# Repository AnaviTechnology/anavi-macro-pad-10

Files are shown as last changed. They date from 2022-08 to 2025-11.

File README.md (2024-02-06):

# ANAVI Macro Pad 10

**Open source programmable keypad with 9 mechanical switches and a rotary encoder.**

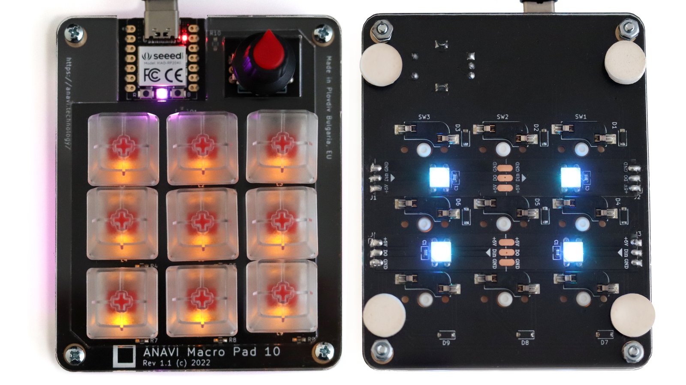
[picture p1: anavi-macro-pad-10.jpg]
ANAVI Macro Pad 10


ANAVI Macro Pad 10 is an open source, custom-programmable, mini keyboard/keypad.

ANAVI Macro Pad 10 has been designed with [the cross platform and open source electronics design automation suite KiCad](https://kicad.org/). Compatible with [KMK firmware](https://github.com/KMKfw/kmk_firmware/tree/master/boards/anavi/macro-pad-10) and [QMK firmware](https://github.com/qmk/qmk_firmware/tree/master/keyboards/anavi).

[ANAVI Macro Pad 10, ANAVI Knob 1 and ANAVI Knobs 3 were brought to market through a crowdfunding campaign at Crowd Supply](https://www.crowdsupply.com/anavi-technology/anavi-macro-pad-10). For more details please visit https://anavi.technology/

# License

The project is released under the [Creative Commons Attribution-ShareAlike 4.0 International (CC BY-SA 4.0)](https://creativecommons.org/licenses/by-sa/4.0/).

Note: This is a human-readable summary of (and not a substitute for) the [license](https://creativecommons.org/licenses/by-sa/4.0/legalcode).

You are free to:

Share — copy and redistribute the material in any medium or format Adapt — remix, transform, and build upon the material for any purpose, even commercially. The licensor cannot revoke these freedoms as long as you follow the license terms. Under the following terms:

Attribution — You must give appropriate credit, provide a link to the license, and indicate if changes were made. You may do so in any reasonable manner, but not in any way that suggests the licensor endorses you or your use. ShareAlike — If you remix, transform, or build upon the material, you must distribute your contributions under the same license as the original. No additional restrictions — You may not apply legal terms or technological measures that legally restrict others from doing anything the license permits. Notices:

You do not have to comply with the license for elements of the material in the public domain or where your use is permitted by an applicable exception or limitation. No warranties are given. The license may not give you all of the permissions necessary for your intended use. For example, other rights such as publicity, privacy, or moral rights may limit how you use the material.

You will have to provide a link to the original creator of the project http://www.anavi.technology on any documentation or website.

Credit can be attributed through a link to the creator website: http://www.anavi.technology

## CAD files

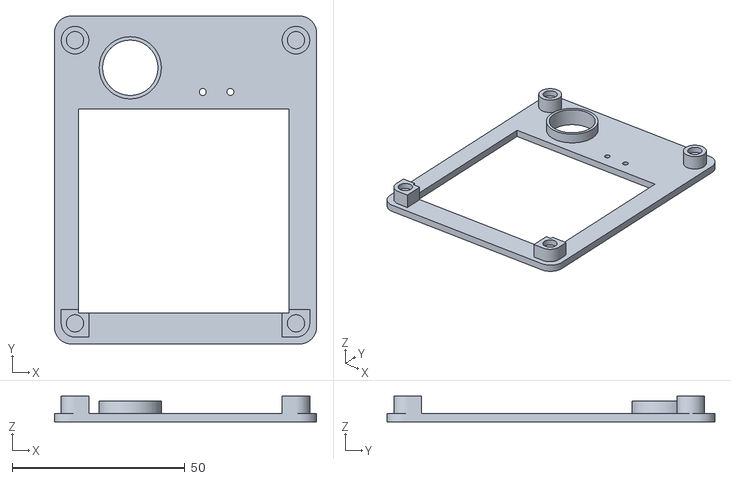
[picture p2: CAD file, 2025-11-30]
case/anavi-macro-pad-10-top.stl
76.0 x 95.0 x 7.50

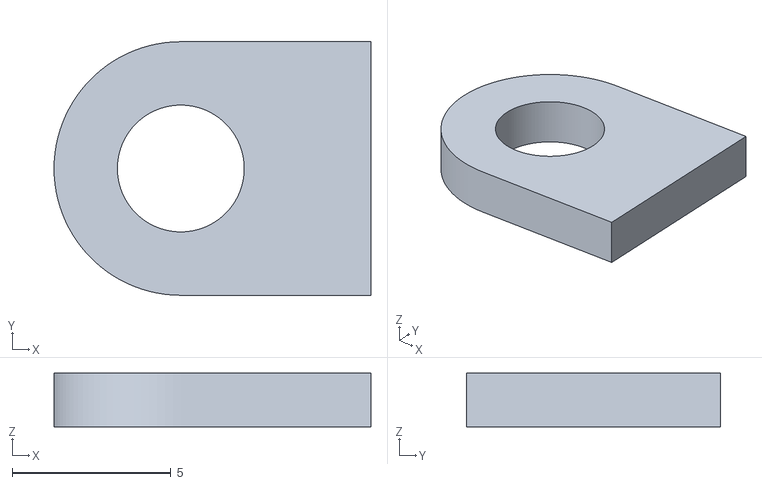
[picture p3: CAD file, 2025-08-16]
case/keyboard-spacer-17.stl
10.0 x 8.00 x 1.70

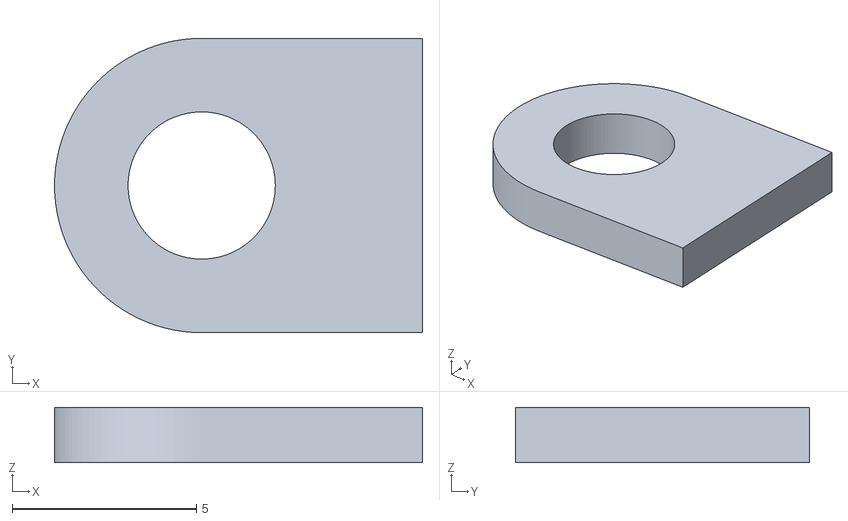
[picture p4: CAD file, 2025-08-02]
case/keyboard-spacer.stl
10.0 x 8.00 x 1.50

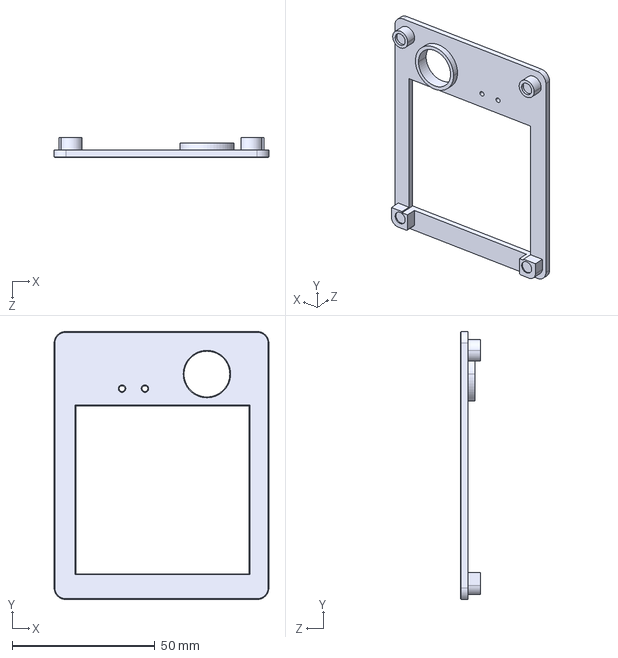
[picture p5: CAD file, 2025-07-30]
case/anavi-macro-pad-10-case-top.step
75.2 x 93.8 x 7.10 mm

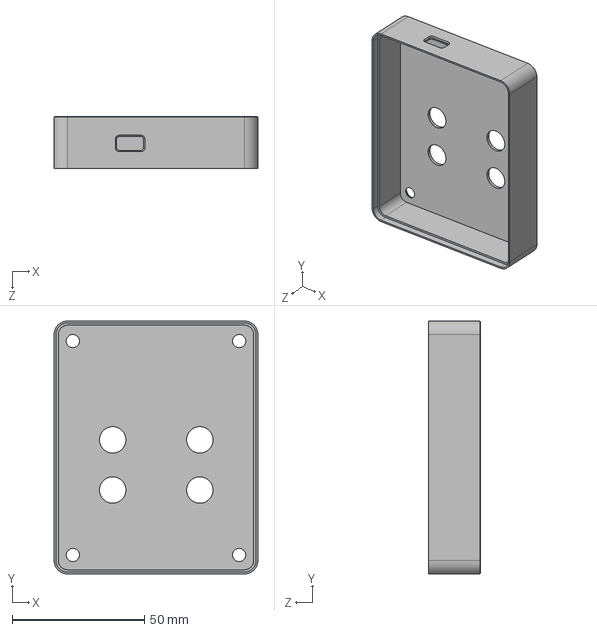
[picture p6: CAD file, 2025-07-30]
case/anavi-macro-pad-10-case-bottom.step
77.2 x 95.8 x 19.7 mm

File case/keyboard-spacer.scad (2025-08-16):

// Settings

// Height of the keyboard spacer
height = 1.7;
// Outer diameter of the main cylinder
outer_d = 8;
// Diameter of the hole
inner_d = 4;
// Width of the rectangular extension
rect_w = 6;
// Height (depth in X-Y) of the rectangular extension
rect_h = 8;

module base_shape() {
    difference() {
        union() {
            // Main cylinder
            cylinder(h=height, d=outer_d, $fn=100);
            
            // Rectangular cuboid on the right
            // which starts at the middle of the cylinder
            translate([0, -rect_h/2, 0])
                cube([rect_w, rect_h, height]);
        }

        // Inner hole
        cylinder(h=height + 0.1, d=inner_d, $fn=100);
    }
}

// Render the 3D object
base_shape();

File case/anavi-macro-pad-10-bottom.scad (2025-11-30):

// ========================
// Parameters
// ========================
corner_r = 5;    // PCB corner radius

wall_thickness = 2;  // Wall thickness
$fn = 64;              // smooth corners


// Case
case_width = 78;
case_lenght = 97;
case_height = 20;

// Outer cylinder
outer_r = 3;
outer_h = 4;

// Inner hole
hole_r = 3;
hole_h = 2;

// USB-C connector
usbc_l = 10;
usbc_h = 5;

// LED
led_r = 5;

// increase for smoother cone ($fn)
segments = 64;

// ========================
// Case Top Module
// ========================
module case_top() {

    // Translate so inner PCB pocket starts at (0,0)
    translate([corner_r, corner_r, 0]) {
        difference() {
            // Outer shell (walls included)
            linear_extrude(height = case_height)
                rounded_rect(case_width,
                             case_lenght,
                             corner_r);

            // Main hollow interior
            translate([wall_thickness, wall_thickness, wall_thickness])
                linear_extrude(height = case_height-3)
                    rounded_rect(case_width-2*wall_thickness, case_lenght-2*wall_thickness, corner_r);
            
            // Top hollow interior
            translate([wall_thickness/2, wall_thickness/2, case_height-3])
                linear_extrude(height = 3)
                    rounded_rect(case_width-wall_thickness, case_lenght-wall_thickness, corner_r);

            // Mounting hole 1 (top left)
            translate([2, case_lenght-4.5-hole_r*3, 0])
                // Cone
                cylinder(wall_thickness, hole_r, hole_h, center = false, $fn = segments);
            
            // Mounting hole 2 (top right)
            translate([case_width-4.5-hole_r*3+1, case_lenght-4.5-hole_r*3, 0])
                // Cone
                cylinder(wall_thickness, hole_r, hole_h, center = false, $fn = segments);

            // Mounting hole 2 (top right)
            translate([case_width-4.5-hole_r*3+1, hole_h, 0])
                // Cone
                cylinder(wall_thickness, hole_r, hole_h, center = false, $fn = segments);
            
            // Mounting hole 4 (bottom left)
            translate([2, 2, 0])
                // Cone
                cylinder(wall_thickness, hole_r, hole_h, center = false, $fn = segments);
                
            // WS2812B LEDs
            
            // LED bottom left
            translate([17.5, 27, 0])
                cylinder(h = wall_thickness, r = led_r, $fn = segments);
                
            // LED top left
            translate([17.5, 46, 0])
                cylinder(h = wall_thickness, r = led_r, $fn = segments);
                
            // LED bottom right
            translate([50.5, 27, 0])
                cylinder(h = wall_thickness, r = led_r, $fn = segments);
            
            // LED top right
            translate([50.5, 46, 0])
                cylinder(h = wall_thickness, r = led_r, $fn = segments);
            
        }
    }
}

// ========================
// Rounded rectangle module
// ========================
module rounded_rect(x, y, radius) {
    minkowski() {
        square([x - 2*radius, y - 2*radius], center = false);
        circle(r = radius, $fn = $fn);
    }
}

// ========================
// Mounting hole
// ========================
module mounting_hole() {
    difference() {
        // Outer cylinder
        cylinder(h = outer_h, r = outer_r, $fn = 64);
        
        // Inner hole
        translate([0, 0, outer_h-hole_h])  // hole starts at base
            cylinder(h = hole_h, r = hole_r, $fn = 64);
    }
}

module usbc() {
    rotate([90,0,0])
        linear_extrude(height = wall_thickness)
            rounded_rect(usbc_l,usbc_h,1);
}

// ========================
// Top case
// ========================

difference() {
    // Main part of the case
    case_top();  
    // USB-C connector
    translate([1+24, case_lenght, 1+7.8])
       usbc();
}

// ========================
// Visual Tests
// ========================
/*
// Check LED bottom left
translate([0, 27, -10])
    cube([17.5, 10, 30]);

// Check LED top left
translate([0, 46, -10])
    cube([17.5, 10, 30]);

// Check USB-C shorter distance
translate([0, case_lenght, -10])
    cube([24, 4.5, 30]);

// Check USB-C height from bottom
translate([0, case_lenght, 0])
    cube([34, 4.5, 7.8]);

// Check mounting hole 1
translate([0, case_lenght-4.5-20, -10])
    cube([4.5, 20, 30]); 
translate([0, case_lenght-4.5, -10])
    cube([20, 4.5, 30]);

// Check mounting hole 2
translate([case_width-4.5, case_lenght-4.5-20, -10])
    cube([4.5, 20, 30]); 
translate([case_width-20, case_lenght-4.5, -10])
    cube([20, 4.5, 30]);

// Check mounting hole 3
translate([case_width-4.5, 0, -10])
    cube([4.5, 20, 30]); 
translate([case_width-20, 0, -10])
    cube([20, 4.5, 30]);

// Check mounting hole 4
translate([0, 0, -10])
    cube([4.5, 20, 30]); 
translate([0, 0, -10])
    cube([20, 4.5, 30]);
*/

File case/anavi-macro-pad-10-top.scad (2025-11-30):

// ========================
// Parameters
// ========================
// PCB corner radius
corner_r = 5;    
// Wall thickness
wall_thickness = 2;  
// smooth corners
$fn = 64;              


// Case (2 mm shorter than the bottom, aka 1 mm on each side)
case_width = 76;
case_lenght = 95;
case_height = 2.5;

// Outer cylinder
outer_r = 4;
outer_h = 5;

// Inner hole
hole_r = 2.5;
hole_h = 2;

// USB-C connector
usbc_l = 10;
usbc_h = 5;

// LED
led_r = 5;

// increase for smoother cone ($fn)
segments = 64;

// ========================
// Case Top Module
// ========================

module case_top() {
    difference() {
        
        // Translate so inner PCB pocket starts at (0,0)
        union() {
            
            translate([corner_r, corner_r, 0])
            // Outer shell (walls included)
            linear_extrude(height = case_height)
                rounded_rect(case_width,
                             case_lenght,
                             corner_r);
            
            // Rotary encoder border
            translate([13+9, 71+9, 0])
                cylinder(6, 9, 9, $fn = segments);
            
            // Bottom left
            translate([2, 2, case_height])
                mounting_hole(true);
            
            // Bottom right
            translate([case_width-2*outer_r-2, 2, case_height])
                mounting_hole(false);
            
            // Top left
            translate([2, case_lenght-2*outer_r-3, case_height])
                mounting_hole_round();
            
            // Top right
            translate([case_width-2*outer_r-2, case_lenght-2*outer_r-3, case_height])
                mounting_hole_round();
        }
        
        // Inner hollow segment of the keycaps
        translate([7, 9, 0])
            cube([61, 59, 30]);
        
        // Opening for the rotary encoder
        translate([14+8, 72+8, 0])
            cylinder(6, 8, 8, $fn = segments);
        
        // Openings for the buttons
        translate([43, 73, 0])
            cylinder(3, 1, 1, $fn = segments);
        
        translate([51, 73, 0])
            cylinder(3, 1, 1, $fn = segments);
    }
    
}

// ========================
// Rounded rectangle module
// ========================
module rounded_rect(x, y, radius) {
    minkowski() {
        square([x - 2*radius, y - 2*radius], center = false);
        circle(r = radius, $fn = $fn);
    }
}

// ========================
// Mounting holes
// ========================
module mounting_hole_round() {
    // Position at start
    translate([outer_r, outer_r, 0]) {
        difference() {
            // Outer cylinder
            cylinder(h = outer_h, r = outer_r, $fn = segments);
            
            // Inner hole
            translate([0, 0, outer_h-hole_h])
                cylinder(h = hole_h, r = hole_r, $fn = segments);
        }
    }
}

module mounting_hole(left = true) {
    tr = left ? 0 : -outer_r;
    // Position at start
    translate([outer_r, outer_r, 0]) {
        difference() {
            
            union() {
                // Outer cylinder
                cylinder(h = outer_h, r = outer_r, $fn = segments);
                translate([tr, -outer_r, 0])
                    cube([4, 8, outer_h]);
                translate([-outer_r, 0, 0])
                    cube([8, 4, outer_h]);
            }
            
            // Inner hole
            translate([0, 0, outer_h-hole_h])
                cylinder(h = hole_h, r = hole_r, $fn = segments);
        }
    }
}

// ========================
// Top case
// ========================

case_top();

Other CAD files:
case/anavi-macro-pad-10-case-bottom.stl
case/anavi-macro-pad-10-case-top.stl

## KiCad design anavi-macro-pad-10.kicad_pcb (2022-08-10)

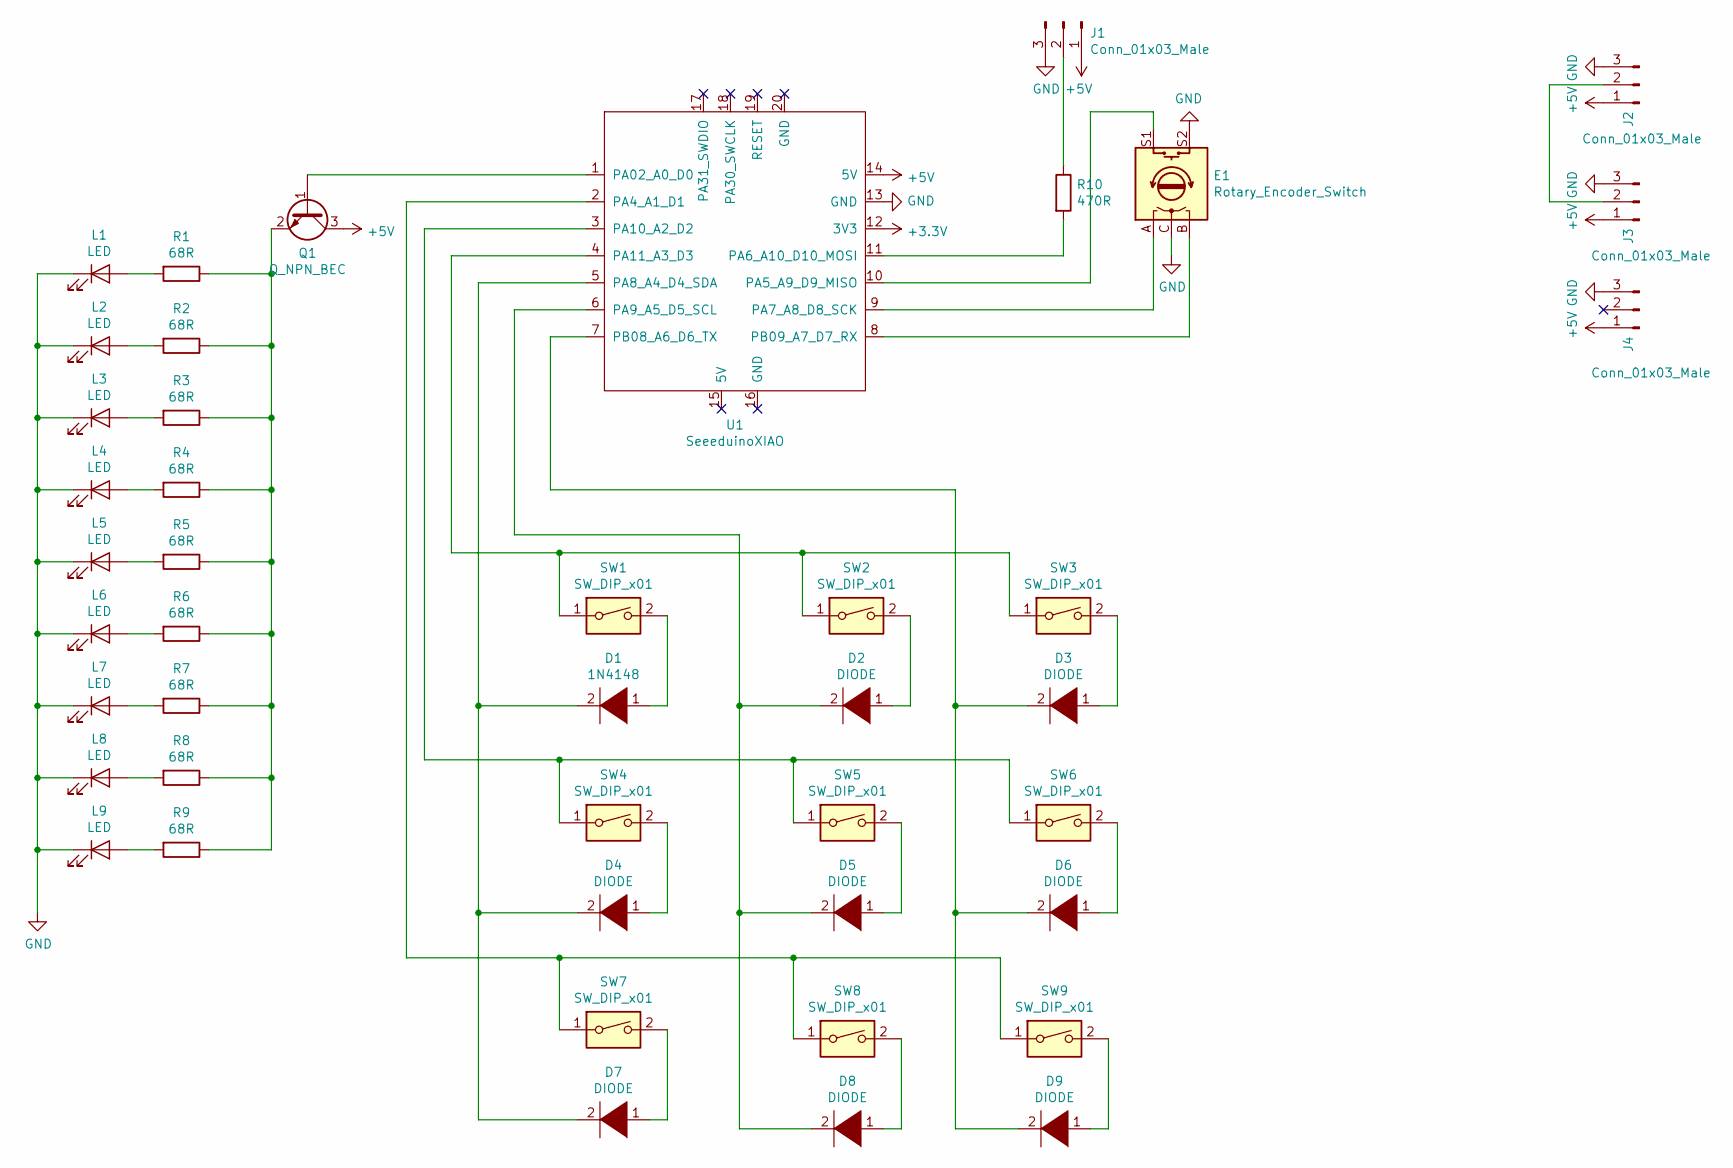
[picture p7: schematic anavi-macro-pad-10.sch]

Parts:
D1: 1N4148; D_SOD-123
D2, D3, D4, D5, D6, D7, D8, D9: DIODE; D_SOD-123
E1: Rotary_Encoder_Switch; RotaryEncoder_Alps_EC11E-Switch_Vertical_H20mm
J1, J2, J3, J4: Conn_01x03_Male; LedConnector_1x03_P2.54mm
L1, L2, L3, L4, L5, L6, L7, L8, L9: LED; LED_1206_3216Metric
Q1: Q_NPN_BEC; SOT-23
R1, R2, R3, R4, R5, R6, R7, R8, R9: 68R; R_0603_HandSoldering
R10: 470R; R_0603_HandSoldering
SW1, SW2, SW3, SW4, SW5, SW6, SW7, SW8, SW9: SW_DIP_x01; Kailh_socket_MX
U1: SeeeduinoXIAO; Seeeduino XIAO-MOUDLE14P-2.54-21X17.8MM

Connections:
+5V: J1.1, J2.1, J3.1, J4.1, Q1.3 (C), U1.14 (5V)
GND: E1.C, E1.S2, J1.3, J2.3, J3.3, J4.3, L1.1 (K), L2.1 (K), L3.1 (K), L4.1 (K), L5.1 (K), L6.1 (K), L7.1 (K), L8.1 (K), L9.1 (K), U1.13 (GND)
unnamed: D1.1 (K), SW1.2
unnamed: D1.2 (A), D4.2 (A), D7.2 (A), U1.5 (PA8_A4_D4_SDA)
unnamed: D2.1 (K), SW2.2
unnamed: D2.2 (A), D5.2 (A), D8.2 (A), U1.6 (PA9_A5_D5_SCL)
unnamed: D3.1 (K), SW3.2
unnamed: D3.2 (A), D6.2 (A), D9.2 (A), U1.7 (PB08_A6_D6_TX)
unnamed: D4.1 (K), SW4.2
unnamed: D5.1 (K), SW5.2
unnamed: D6.1 (K), SW6.2
unnamed: D7.1 (K), SW7.2
unnamed: D8.1 (K), SW8.2
unnamed: D9.1 (K), SW9.2
unnamed: E1.A, U1.9 (PA7_A8_D8_SCK)
unnamed: E1.B, U1.8 (PB09_A7_D7_RX)
unnamed: E1.S1, U1.10 (PA5_A9_D9_MISO)
unnamed: J1.2, R10.1
unnamed: J2.2, J3.2
unnamed: L1.2 (A), R1.2
unnamed: L2.2 (A), R2.2
unnamed: L3.2 (A), R3.2
unnamed: L4.2 (A), R4.2
unnamed: L5.2 (A), R5.2
unnamed: L6.2 (A), R6.2
unnamed: L7.2 (A), R7.2
unnamed: L8.2 (A), R8.2
unnamed: L9.2 (A), R9.2
unnamed: Q1.1 (B), U1.1 (PA02_A0_D0)
unnamed: Q1.2 (E), R1.1, R2.1, R3.1, R4.1, R5.1, R6.1, R7.1, R8.1, R9.1
unnamed: R10.2, U1.11 (PA6_A10_D10_MOSI)
unnamed: SW1.1, SW2.1, SW3.1, U1.4 (PA11_A3_D3)
unnamed: SW4.1, SW5.1, SW6.1, U1.3 (PA10_A2_D2)
unnamed: SW7.1, SW8.1, SW9.1, U1.2 (PA4_A1_D1)

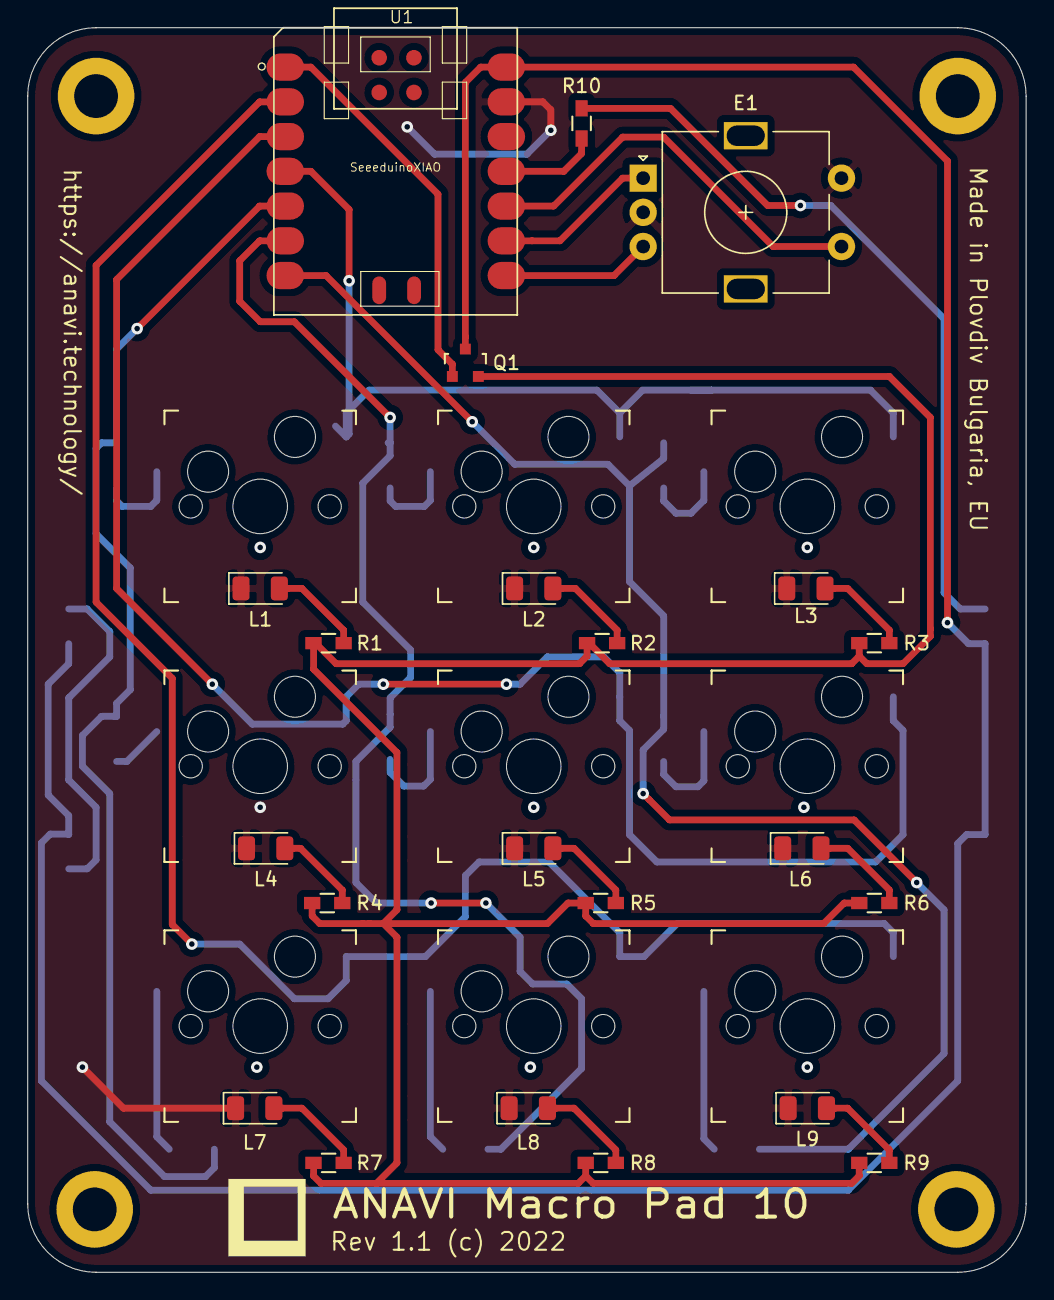
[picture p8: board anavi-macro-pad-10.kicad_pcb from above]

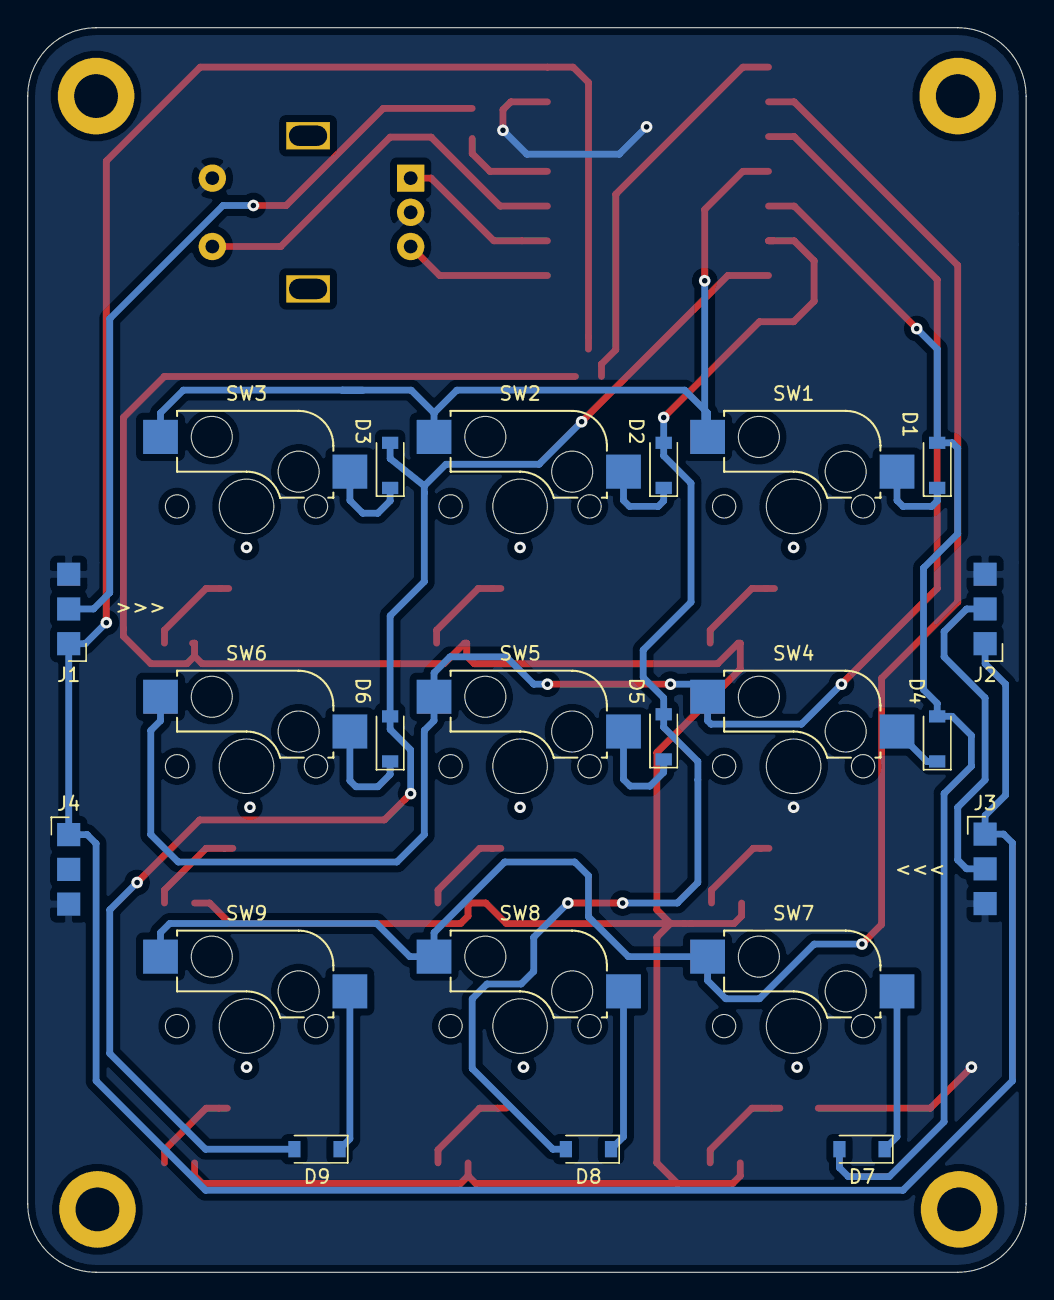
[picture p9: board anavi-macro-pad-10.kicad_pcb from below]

Board: 2 copper layers, 73.0 x 91.0 mm, 44 parts (13 on the bottom side), 34 nets.

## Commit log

2022-06-28 Initial commit
    ANAVI Macro Pad 10 work in progress.
    [anavi-macro-pad-10.kicad_pcb, anavi-macro-pad-10.sch]
2022-07-04 anavi-macro-pad-10.sch: Add LEDs
    Add LEDs for backlit and underlighting.
    [anavi-macro-pad-10.sch]
2022-07-06 components: Add LED and hot-swap connectors
    Add new components:
    - LED connector for WS2812B LED strips
    - Hot-swap connector for mechanical switches
2022-07-06 anavi-macro-pad-10: Create PCB
    Create printed circuit board.
    [anavi-macro-pad-10.kicad_pcb, anavi-macro-pad-10.sch]
2022-07-17 anavi-macro-pad-10.kicad_pcb: Finalize PCB
    [anavi-macro-pad-10.kicad_pcb]
2022-07-22 anavi-macro-pad-10.kicad_pcb: Rev 1.1
    Rev 1.1 of ANAVI Macro Pad 10 with hardware fixes for the WS2812B
    LED strips.
    [anavi-macro-pad-10.kicad_pcb]
2022-08-10 anavi-macro-pad-10.kicad_pcb: Enclosures
    Draw enclosures on the fabrication layer.
    [anavi-macro-pad-10.kicad_pcb]
2024-02-06 README.md: Fix KiCad URL
2025-07-30 case: Add STL and STEP files
    Include STL and STEP files for 3D printing a case for the ANAVI
    Macro Pad 10, designed by Pavlin Saksanov.
    [anavi-macro-pad-10-case-bottom.step, anavi-macro-pad-10-case-bottom.stl, anavi-macro-pad-10-case-top.step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]
2025-08-02 case: Add keyboard spacer
    Add a keyboard spacer. Four of these should be placed between the
    printed circuit board and the bottom acrylic part when assembling
    together the 3D printed case for ANAVI Macro Pad 10.
    [keyboard-spacer.scad, keyboard-spacer.stl]
2025-08-16 keyboard-spacer: Increase height to 1.7mm
    Increase height from 1.5mm to 1.7mm.
    [keyboard-spacer-17.stl, keyboard-spacer.scad]
2025-11-30 anavi-macro-pad-10-bottom.scad: OpenSCAD
    The bottom part of ANAVI Macro Pad 10 3D printed case re-designed
    in OpenSCAD. Its dimensions were slightly increased to 97x78x20mm
    to account for 2 mm and 1 mm wall thicknesses.
    [anavi-macro-pad-10-bottom.scad]
2025-11-30 anavi-macro-pad-10-bottom.scad: Adjust top wall
    Adjust the height of the top wall to 3 mm.
    [anavi-macro-pad-10-bottom.scad]
2025-11-30 anavi-macro-pad-10-top.scad: OpenSCAD
    The top part of ANAVI Macro Pad 10 3D printed case re-designed
    in OpenSCAD. Its dimensions were slightly increased to 76x95x2.5mm
    to match the re-designed bottom part.
    [anavi-macro-pad-10-top.scad, anavi-macro-pad-10-top.stl]

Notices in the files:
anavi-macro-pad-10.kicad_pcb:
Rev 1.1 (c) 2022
